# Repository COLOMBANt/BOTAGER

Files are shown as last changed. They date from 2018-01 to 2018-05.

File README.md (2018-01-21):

# BOTAGER

polytech logo polytech 
Ce projet est réalisé dans le cadre de la formation de prépa intégrée de Polytech'Nice Sophia 

<h1>Description</h1>

Le BOTAGER est un robot qui pourra se déplacer sur un potager pour planter différentes plantes.
L'utilisateur donne les instructions au robot à travers une application smartphone, il peut choisir les types de plantes, et leur disposition sur le terrain.

Le robot quand à lui pourra se repérer sur le terrain grâce à 4 piquets plantés sur chaque coin pour délimiter le terrain

<h1>Matériel</h1>

+ 4 modules HELTEC LoRa Bluetooth (1 pour chaque piquet)  
+ Carte Arduino  
+ Un système de sélection de graines
+ Squelette du robot
+ Un smartphone

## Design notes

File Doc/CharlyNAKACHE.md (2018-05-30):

# Cahier de suivi du projet de Charly NAKACHE

* Séance du 20 Décembre 2017 

J'ai formé mon groupe avec Dimitri DAVID et Thomas COLOMBAN. 
Nous sommes partis sur une idée de robot piloté par smartphone qui servirait à planter un potager.
L'utilisateur pourra choisir l'organisation du potager (Type de graines/Emplacement des plantes)

Nous avons défini le planning des prochains mois, nous nous sommes répartis les différentes tâches et
nous avons fait un diagramme fonctionnel du projet.

* Séance du 12 Janvier 2018
 
 Lors de la répartition des tâches j'ai choisi le côté plus mécanique que informatique, c'est à dire le
 chassis du robot, sons système de propulsion mais aussi le tri des différents graînes et la méthode pour les planter.

 J'ai effectué des recherches pour avoir une idée du squelette du robot, je pensais à un chassis plat (pour placer
 simplement les composants), 4 grosses roues avec des pneus "tout-terrain" (chenilles non nécéssaires pour un si petit
 robot), d'une taille d'environ 15cm² pour placer les différents composants que j'aurai besoin pour le plantage, mais
 aussi ceux que mes collaborateurs auront besoin  de placer sur le robot.
 
 J'ai alors demandé à Monsieur Ferrerro si il y avait des squelettes de robots à disposition et il m'en a proposé un qui
 me parait très bien pour ce que j'ai à faire, les moteurs sont déjà placés et soudés, les pneus sont bien larges et ont
 l'air d'avoir une bonne adhérance à la terre.

* Séance du 19 Janvier 2018

J'ai commencé à imaginer le système de tri des graines et de méthode de plantation.
Les graines seront dans des compartiments différents placés en ligne, un actionneur linéaire et une pompe à air (attachés à un socle)
se déplaceront au dessus des différents compartiments grâce à un système de rails reliés à un moteur.
Pour attraper seulement une ou deux graines, j'utilise la pompe à air, il y aura un petit orifice au bout de mon système pour que
la graine soit aspirée et reste collée au bout du système.
J'ai donc fait des recherches pour les différents composants que j'ai besoin.

* Séance du 23 Janvier 2018

Nous avons fait notre présentation orale.
Durant la semaine j'ai réfléchi à un autre système pour le déplacement de mon actionneur linéaire et de la pompe, je pensais à un
système de courroie et poulies où le socle serait accroché. J'ai donc fait des recherches pour la courroie avant d'envoyer ça
Mr Masson.

* Séance du 6 février

Durant la séance, j'ai fait différents schémas pour réfléchir et visualiser mon mécanisme. De plus, j'ai fait des recherches sur
les moteurs de la pompe à air que j'ai commandé, je me suis rendu compte que cette pompe était finalement une souffleuse 
et non pas une pompe. Par chance, Mr Masson disposait d'une pompe (un peu plus puissante en plus) que j'ai pu récupéré.

* Séance du 22 février

J'ai continué les recherches  sur la pompe et l'utilisation de cette dernière avec le uln2803.

* Séance du 15 mars 

Modélisation rapide en 3d du robot.
Mr. Masson nous donne un moteur pas à pas.
Problème avec actionneur linéaire, erreur dans les dimensions.
Recherches sur le type de batterie nécessaire et la capacité.

* Séance du 27 mars

Diaporama et présentation orale.
Mr. Masson nous donne une batterie.

* Séance du 04 avril

En attente de l'actionneur j'ai aidé dimitri pour des recherches pendant le cours.
Recherches sur le fonctionnement de la batterie.
Recherches sur le moteur pas à pas et pont en H.

* Séance du 17 avril

Sofab :
on a démonté et remonté le robot en y ajoutant la structure nécessaire (bois).
Impression de pièces 3D pour les graines et les rails (pour le déplacement de l'actionneur)

* Séance du 02 mai

Modélisation d'un système 3d permettant de fixer l'actionneur.
Sofab :
Ajout de la courroie fixée au rail, et de pièces en bois pour fixer le moteur pas à pas, mais aussi de cales pour tendre la courroie.

* Séance du 07 mai

Problèmes concernant la pièce qu'on voulait fixer au bout de l'actionneur pour y mettre le tube de la pompe à air,
l'imprimante 3d ne peut faire un objet aussi petit et précis.
Plus tard, problèmes de couple avec le moteur pas à pas, il n'y a pas assez de puissance.

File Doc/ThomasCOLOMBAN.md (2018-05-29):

# Cahier de suivi du projet de Thomas COLOMBAN

* Séance du 20 Décembre 2017 

J'ai formé mon groupe avec Dimitri DAVID et Charly NAKACHE. 
Nous sommes partis sur une idée de robot piloté par smartphone qui servirait a planter un potager.
L'utilisateur pourra choisir l'organisation du potager (Type de graines/Emplacement des plantes)

Nous avons défini le planning des prochains mois et nous nous sommes répartis les différentes tâches et
nous avons fait un diagramme fonctionnel du projet.

* Séance du 12 Janvier 2018 

Dans le cadre du projet, je me suis occupé de deux sous-parties :
-	L’application smartphone sous Android qui permet à l’utilisateur de choisir le type de graine à planter, et la disposition des graines sur le champ. 
-	La gestion des 4 moteurs à courant continu pour faire se déplacer le robot.

La plus grande partie de mon travail a été de programmer une application sous Android sur laquelle l’utilisateur peut choisir où et quoi planter comme graines et qui ensuite envoi les informations en Bluetooth à la carte Arduino du robot.
Pour cela j’ai choisi de tout coder moi-même que ce soit le visuel de l’application ou le protocole Bluetooth.
J’ai donc réalisé l’application avec le logiciel Android Studio qui permet de coder des applications pour Android.
Premièrement j’ai dû suivre plusieurs tutoriels pour comprendre le fonctionnement du logiciel, qui est très puissant mais donc assez complexe à prendre en main.

Voici les premiers visuels de l'appli

Image appli 1

Image appli 2

Image appli 3

J’étais partis du principe que le rectangle central représentait le champ, et grâce au bouton inventaire situé en bas on ouvrait l’inventaire avec les différentes plantes (voir 3ème image).
Ensuite en appuyant sur un icone on pourrait faire glisser la plante là où on le souhaite sur le champ.
Il y a aussi un bouton en haut à gauche pour faire apparaitre la liste des appareils Bluetooth.

* Séance du 19 Janvier 2018                        

Rédaction du README.md

J'ai fait ma partie PowerPoint dans la présentation du 23/01.
J'ai aussi commencé l'application sous Android Studio.

* Séance du 23 Janvier 2018

Présentation Orale  
Application sous AndroidStudio

* Séance du 6 février

Après plusieurs semaines passées sur le logiciel j’ai décidé de simplifier certaines fonctions de l’application, à cause de leur complexité et par manque de temps, et d’en ajouter d’autres.
Voici les nouveaux visuels:

interface_1

interface_2

Le champ où l’on va planter les graines sera modélisé par une grille de 16 boutons, car pour simplifier nous partons du principe que le champ sera divisé en 16 carreaux et il est possible de planter une graine dans chaque.
A chaque appui sur un bouton ce dernier change de couleur, pour signifier le type de plante.
Au départ tous les boutons sont grisés et c’est l’utilisateur qui choisis sur quoi appuyer en fonction du résultat qu’il veut. Il y a aussi un bouton Effacer (la croix en haut à gauche) qui va remettre toutes les cases grises, et un bouton Envoyer qui va récupérer la valeur associée à chaque bouton et l’envoi au robot par Bluetooth. 

* Séance du 22 février

Fin de la partie XML de l'application

28942654_430170724103745_731970666_o

28822561_430170720770412_221739668_o

* Séance du 15 mars 

Partie Bluetooth en Java

* Séance du 27 mars

Diaporama et présentation orale 

* Séance du 04 avril

J'ai commencé la partie de gestion des moteurs :
- Recherche de la documentation constructeur  
- Schéma de câblage de l'arduino, de la batterie et de la carte de gestion des moteurs  
    
Mon travail consistait donc à faire les fonctions de base Avancer, Reculer, Rotation et Stop du robot.
J’ai donc dû cabler ensemble les moteurs, la carte L298 V3 et une arduino Uno, et ensuite coder un programme arduino pour réaliser ces fonctions.
    
Ebauche du câblage:
30849423_450469662073851_1439568072_o

* Séance du 17 avril

J’ai tout d’abord rencontré quelques difficultés pour comprendre le fonctionnement de la carte L298 V3. Il y a peu de documentation sur internet de cette carte car une autre carte la L298 V1 est beaucoup plus connue et remplit la même fonction avec seulement 2 entrées moteur au lieu de 4 pour la L298 V3. J’ai donc principalement raisonné par déduction en me basant sur la documentation constructeur de la L298 V1 et j’ai effectué de nombreux tests pour comprendre son fonctionnement.

Soudure des différentes parties de la carte
Problème avec l'alimentation de la carte L298N V3

* Séance du 02 mai

Schéma de câblage final:

cablage

Test de rotation du robot avec le programme du magnétomètre (partie de Charly Nakache)
Le robot arrive bien à se repérer dans l'espace(orientation) et à tourner jusqu'à l'angle indiqué

* Séance du 07 mai

Réglage des derniers bugs sur l'application Android

* 20 mai 

Partie Bluetooth terminée  
Partie gestion des moteurs finie  
Et tout fonctionne !!

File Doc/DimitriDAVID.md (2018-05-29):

# Cahier de suivi du projet de David Dimitri

* Séance du 20 Décembre 2017 

J'ai formé mon groupe avec Thomas COLOMBAN et Charly NAKACHE. 
Nous sommes partis sur une idée de robot piloté par smartphone qui servirait a planter un potager.
L'utilisateur pourra choisir l'organisation du potager (Type de graines/Emplacement des plantes)

Nous avons défini le planning des prochains mois et nous nous sommes répartis les différentes tâches et
nous avons fait un diagramme fonctionnel du projet.

* Vacances de Noël 

J'ai recherché des solutions et voies à explorer pour reussir a positionné le robot dans l'espaces.

* Semaine du 12 Janvier 2018 : 

Familiarisation avec les module LoRa, et élaboration du github.

* Semaine du 19 janvier 2018 :

Réalisation du modèle de notre robot sur inventor.
Premier test des modules Heltec Lora.

* Semaine du 26 janvier 2018 :

Réalisation d'une première maquette virtuelle sur AutoDesk.
Début de la rédaction d'un code de trilatération.

* Semaine  du 2 février 2018 :

Réception des modules commander, premier pas avec eux et encore rédaction du programme de trilatération.

* Semaine du 9 février 2018 :

Après test de mon code de trilatération, je me rend compte que la précision des mesures pouvaient mettre dans un cas où l'étude de l'intersection de 3 cercles ne comportais pas de solutions. Je suis donc à la recherche du solution alternative.

* Semaine du 15 février 2018 :

Après des recherches j'essaye de trouver une méthode utilisant la barycentre pondéré des 3 poteaux pour trouver l'emplacement du mobile. La tache la plus compliqué dans cela est de trouver des coefficients permettant de retrouvé l'emplacement dans tout les cas, je suis donc actuellment en trin d'étudier diverses solutions possibles.

* Semaine du 22 février 2018 :

Beaucoup de problème pour trouver une methode permettant la résolution sytematique du problème. Je pense négliger cette partie pour le moment, je vais pour l'instant faire seulement un solveur d'équation puis si le temps me le permet essayer de retrouver une solution a la fin. Je rencontre aussi beaucoup de probleme avec les codes, les variables numériques ont tendances à s'arrondir lors de convertion d'une façon qu'il ne devrais pas être.

* Semaine du 1 Mars :

Des problèmes d'interference entre les modules, les messages s'enmêle. Je cherche une solution pour s'incroniser les différents envoie de données.

* Semaine du 7 Mars :

Probleme regler, en utilisant des intervalles et la fonction millis. Le temps d'acquisition est certes plus long, mais cela fonctionne parfaitement. Aussi, il me semble qu'un des module presente un default, il refusent de se compiler, même si le codes est fonctionneles sur les autres modules.

* Semaine du 14 mars :

Sur la proposition de monsieur Ferrero je vais integrer une variation de frequence d'envoie dans le systeme afin d'optimiser la mesure de distance. Aussi, il m'as mit a dispostion ses codes qu'il utilisent sur les même modules que moi, domage que ce soit si tard.

* Semaine du 21 mars :

 Finissions du code pour trouver la postion du robot, celui marche même avec les écart de mesures des modules bluetooth.
 Redaction d'un code pour rassembler les données sur le robot.
 
 * Semaine du 28 Mars :
 
 Dessins des plans des pièces à découper ou à imprimer pour la construction de la structure du robot.
 
 * Semaine du 5 Avril :

  Assemblage de la structure du robot avec Charly , et teste des différents éléments mobiles (actionneur, moteur pas à pas, ...)
  
  * Semaine du 12 Avril :
  
  Début de rédaction du programme pour venir chercher et déposer la graine que l'utilisateur à choisit.
  
  * Semaine du 20 Avril :
  
  Etablissement d'une fonction permettant de positionner le robot dans un certain angle choisie, par rapport au repère.
  Utilisation du magnétomètre.
  
  *Semaine du 30 avril :
  
  Nouveau problème dans la communication entre les modules LoRa,source du probleme inconnue, j'ai du reprendre les codes.
  
  * Semaine du 1 mai :
  
  Redaction du programme de deplacment d'un point A à un point B.
  
  * Semaine du 7 mai :
  
  Test de déplacment du robot. Echec à cause de mesure de RSSI variant de plusisuer dizaies de décibels.
  
  * Semaine du 14 mai :
  
  idem que la semaine passé, nous n'arrivons pas à solutionner le problème.
  
  * Semaine du 21 mai :
  
  Redaction d'un programme de démonstration n'utilisant pas la localisation
  
  * Semaine du 28 mai :
  
  Compte rendu et préparation de l'oral, denière finissions, tournage de la vidéo de présentation.

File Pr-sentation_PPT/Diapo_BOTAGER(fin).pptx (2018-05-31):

## BOTAGER

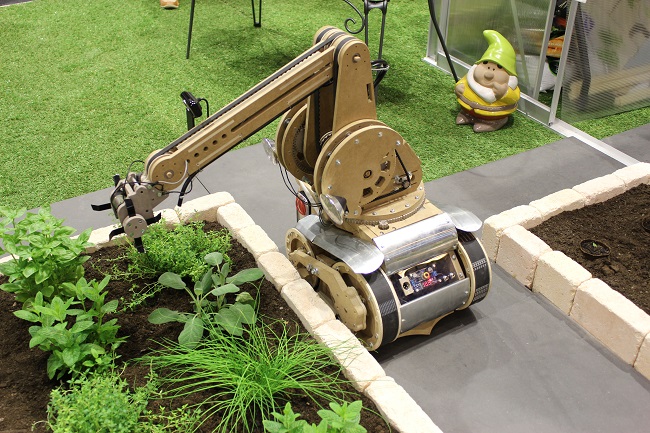
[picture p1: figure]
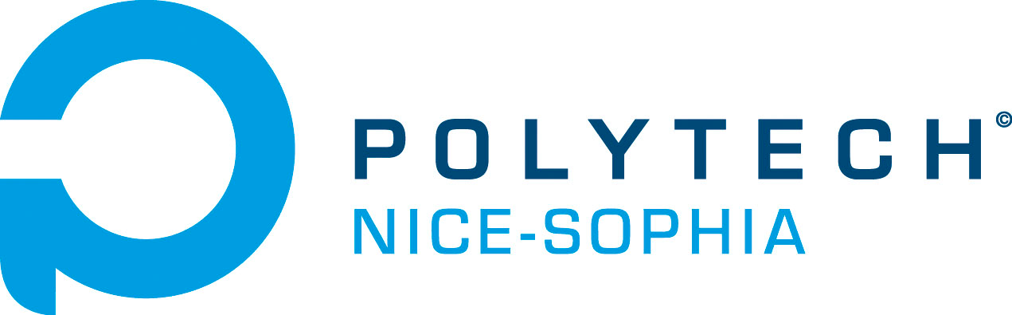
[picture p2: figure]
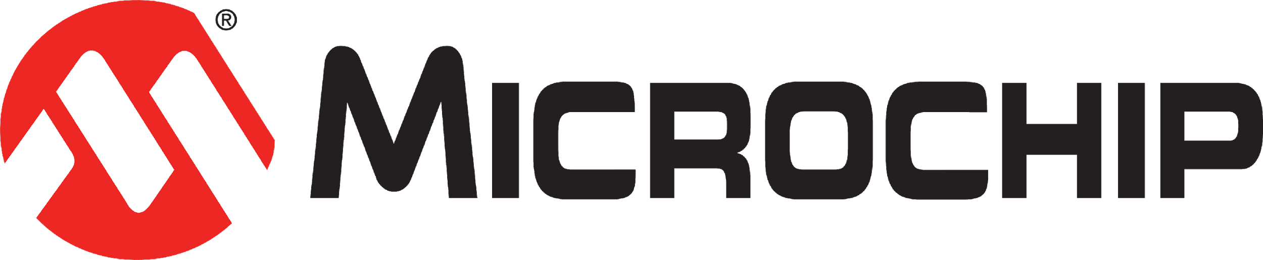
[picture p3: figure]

DAVID Dimitri
NAKACHE Charly
COLOMBAN Thomas

## NOTRE PROJET

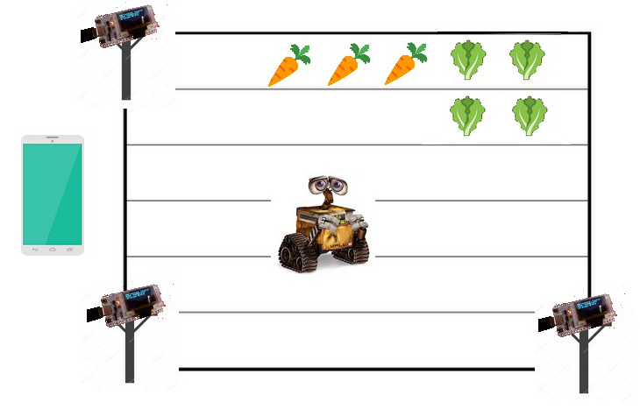
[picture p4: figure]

## REPARTITION DES TACHES

- Application smartphone/Gestion des moteurs Thomas COLOMBAN
- Positionnement/Repérage du robot dans l’espace Dimitri DAVID
- Assemblage du robot Charly NAKACHE

## APPLICATION

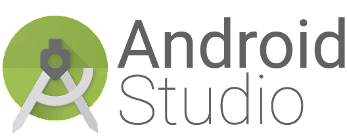
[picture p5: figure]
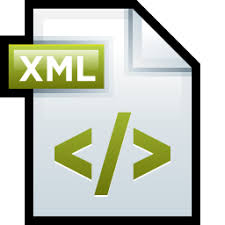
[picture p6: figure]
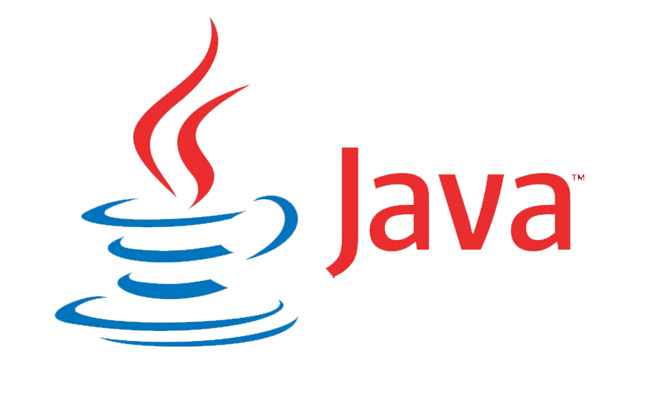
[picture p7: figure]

## APPLICATION

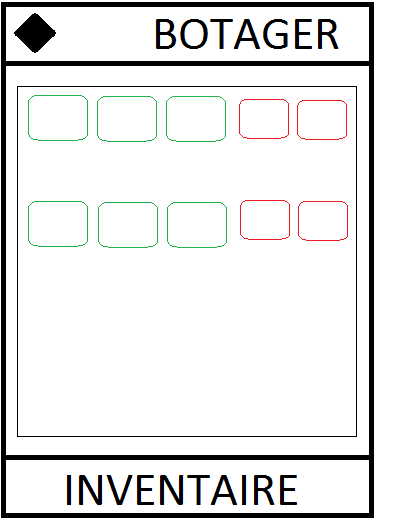
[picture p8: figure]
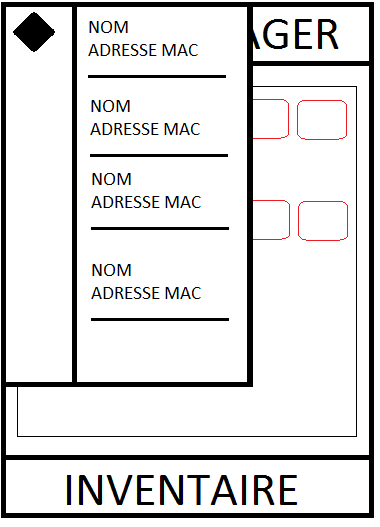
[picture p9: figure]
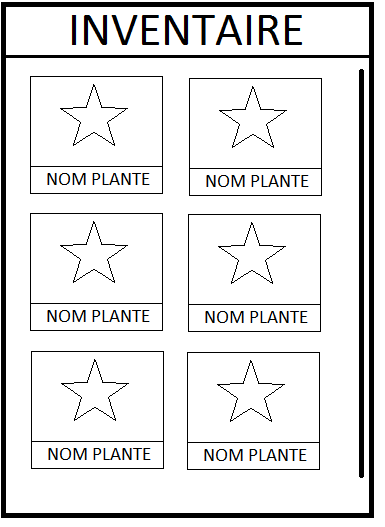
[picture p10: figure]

## APPLICATION

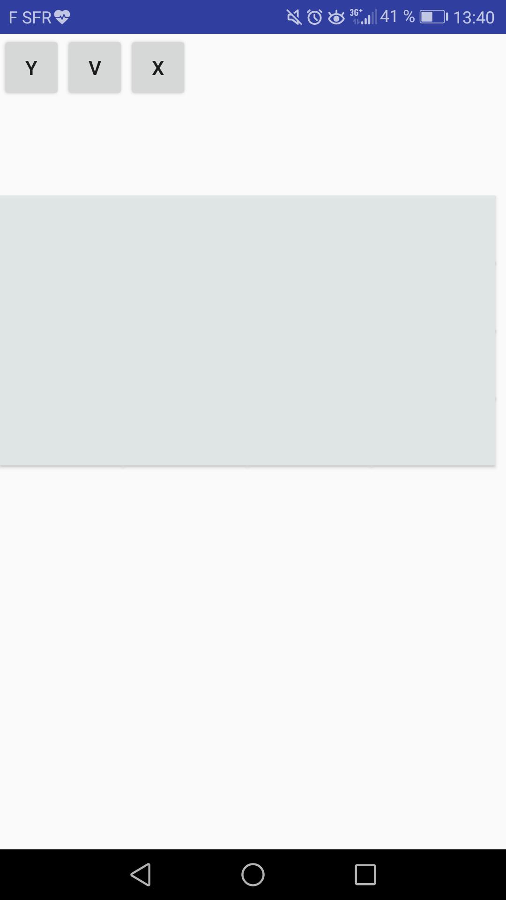
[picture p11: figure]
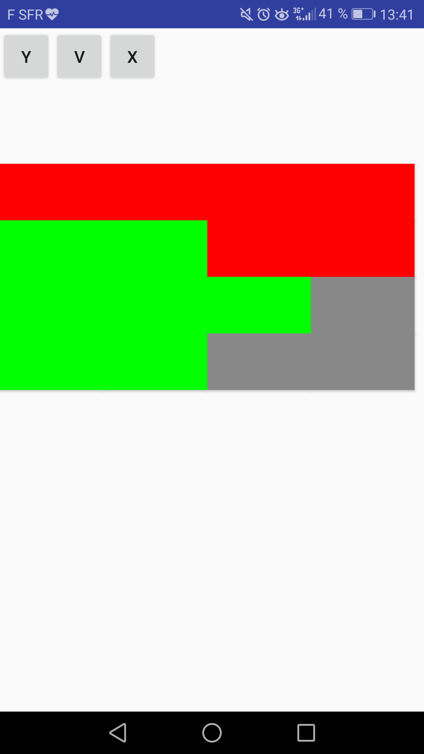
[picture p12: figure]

## APPLICATION

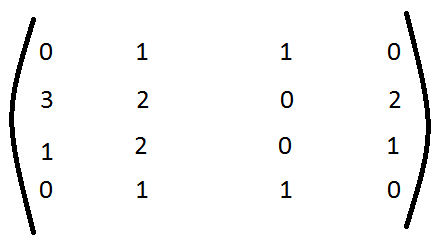
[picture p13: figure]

0: Rien
1: Salade
2: Tomates
3: Oignons
Etc …

## APPLICATION

- Simplification de l’application
- Complexité de la liaison Bluetooth

PROBLEMES :

## GESTION DES MOTEURS

- Avancer();
- Reculer();
- Orientation( Angle );
- Stop();

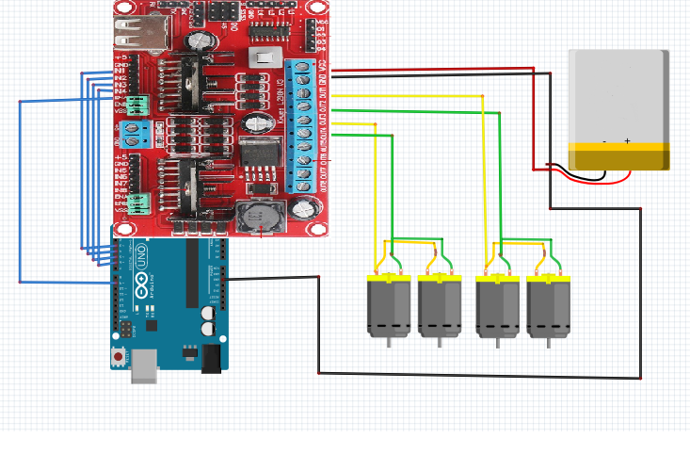
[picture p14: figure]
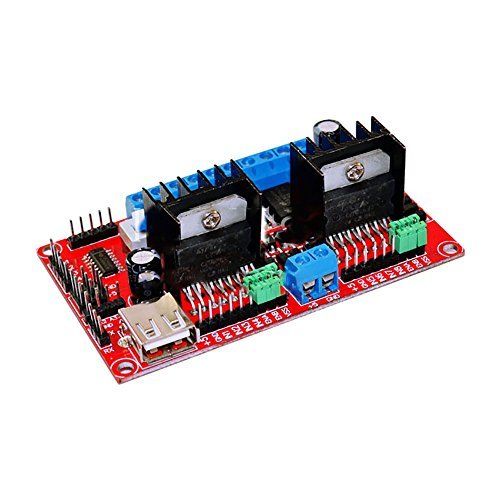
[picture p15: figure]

## POSITIONNEMENT

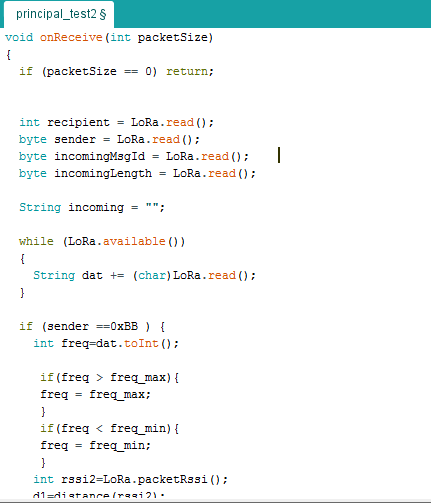
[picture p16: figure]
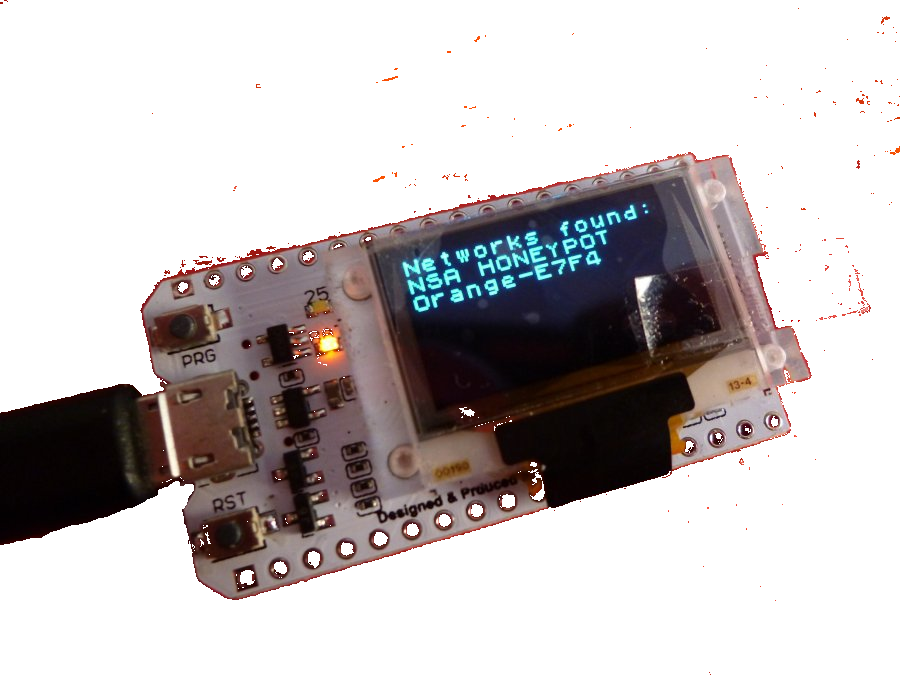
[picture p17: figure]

## POSITIONNEMENT

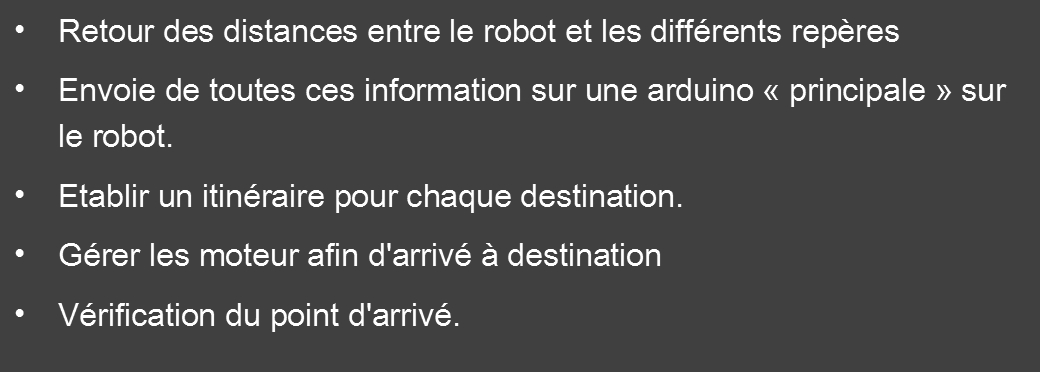
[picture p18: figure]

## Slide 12

POSITIONNEMENT

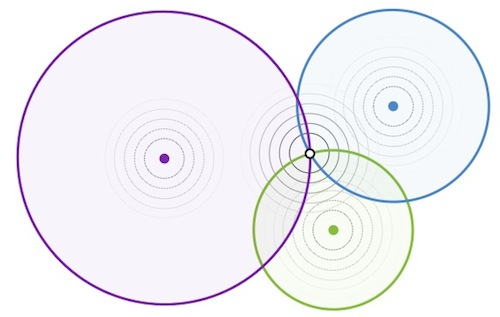
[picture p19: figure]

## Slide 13

POSITIONNEMENT

PROBLEMES :

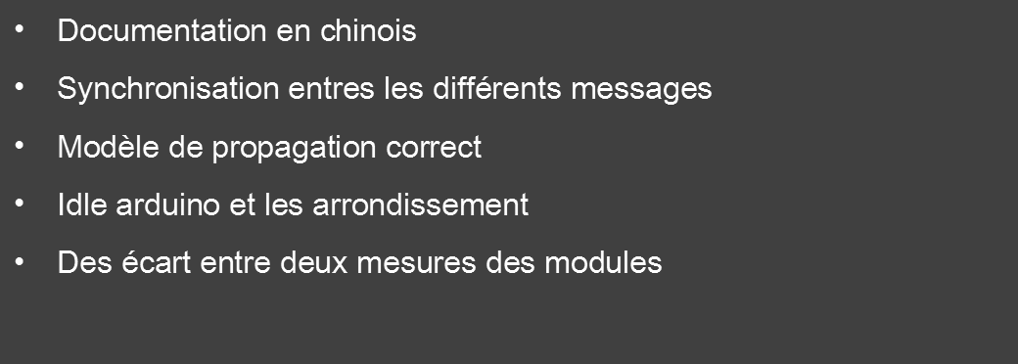
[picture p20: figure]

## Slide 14

NAVIGATION

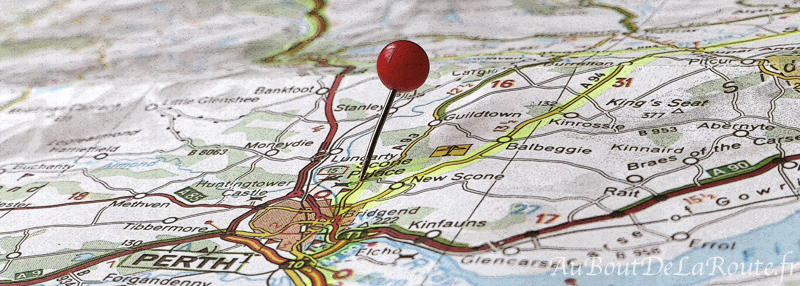
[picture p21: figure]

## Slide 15

POSITIONNEMENT

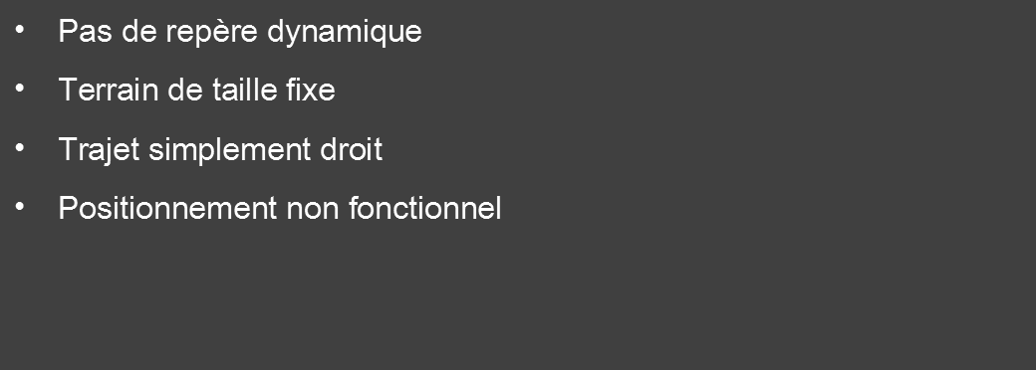
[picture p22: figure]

## ASSEMBLAGE / GESTION DES GRAINES

- Recherches sur la propulsion / forme du robot
- Plans du robot et système de plantation des graines
- Modélisation et impression de pièces 3D

## Mes problèmes

ASSEMBLAGE / GESTION DES GRAINES

- Changements concernant la structure du robot
- Commande de pièces
- Calculs pour certains composants

## CONCLUSION

- Apprendre le travail d’ingénieur
- Apprendre de nombreuses connaissances
- Projet trop ambitieux

## TEST IRL

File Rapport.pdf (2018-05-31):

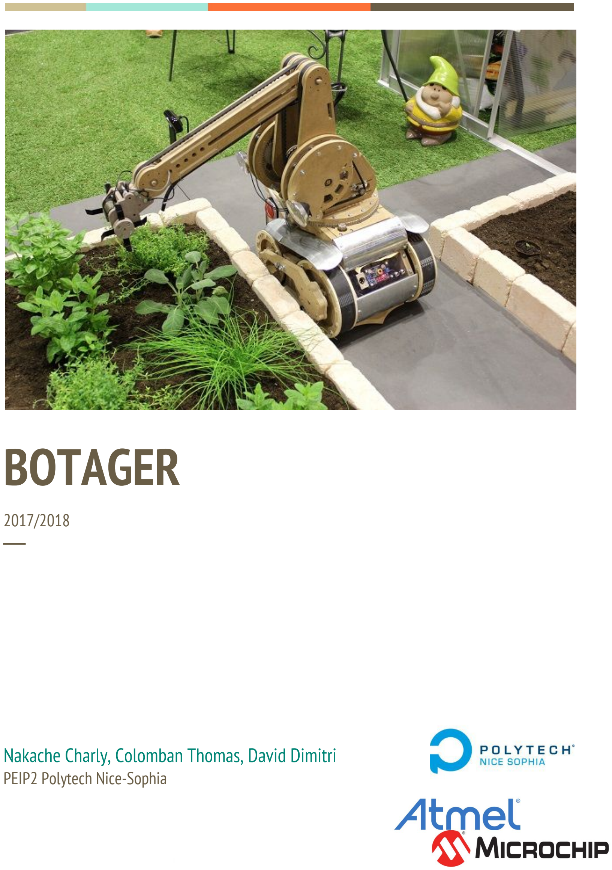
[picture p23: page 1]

# BOTAGER

2017/2018
─

Nakache Charly, Colomban Thomas, David Dimitri PEIP2 Polytech Nice-Sophia

## Sommaire :

I/Notre Projet :

2/Objectifs :

3/Matériel utilisé :

4/Fonctionnement et schéma :

5/Problèmes rencontrés :

6/Conclusion :

## Notre Projet :

Concept :
Nous étions partis sur la recherche d’un moyen permettant de faciliter et de rendre plus accessible les plaisirs du jardin. C’est pourquoi nous avons rapidement choisi de concevoir un robot permettant d’effectuer des tâches répétitives. Nous avons donc centré toutes les fonctionnalités de ce robot autour de ce leitmotiv. Ce robot pourra donc planter des graines au sein d’un terrain délimité à des emplacements définis via une application téléphone. Le repérage s’effectuera via des poteaux de délimitation.

## Our Project :

Concept :
We were looking for a method to simplified and make more accessfull the pleasure of having a little garden. That why we quickly choose to try to conceived a bot that can carry out repetitives task. So we have center all the features of this bot around this goal. This bot will be able to plant seeds anywhere in a delimited ground in spots defined with a smartphone app. The positioning will be using post to landmark and spot the bot.

## Nos Objectifs :

Objectifs à réaliser :
Afin de mener à bien les actions qui lui sont demandé, certaines fonctionnalités s'imposait, en voici la liste :
-Une application téléphone permettant de dialoguer avec le robot afin de lui transmettre ses instructions. Cette application devra être capable de modéliser le terrain sur lequel le robot évoluera, permettre à l’utilisateur de sélectionner les emplacements des plantations et également lui permettre de choisir quelles variétés de plantes il souhaite planter.

-Un châssis permettant au robot d’évoluer dans la terre voir la boue, lui permettant également d’être autonome en énergie, d’apporter avec lui une variété de graines, qui seront sélectionnées d’après les volontés de l’utilisateur et enfin il devra être également capable de transporter un système permettant la plantation.

-Un système de repérage permettant au robot de connaître sa position à tout moment, afin de pouvoir naviguer à l’emplacement voulu. L’utilisation du GPS pour cette tâche est écartée car la résolution nécessaire à cette fonction est beaucoup plus précise. Enfin dans l’idéal ce système aurait été complètement modulable et aurait pû s'adapter à toutes les configurations possibles.

Objectifs atteints :
Au vue de la complexité des objectifs que nous nous étions fixés, nous avons été obligé de simplifier certains d’entre eux. Voici un état des lieux des fonctionnalités opérationnelles à ce jour :

- La modularité des terrains d’action du robot ont été simplifié, nous nous sommes donc attelés à le faire fonctionner sur un terrain carré fixe d’une taille de 12x12 mètres
-Les emplacements de plantations se sont vue réglementés et définie au nombre de 16. Il s’agit donc de zone de 3x3m que le robot essayera d’atteindre en leur centre. Ce changement vient de difficulté dans le codage de l’application, ainsi que de problème de précision dans le repérage du robot. Ses emplacements prédéfinis nous permettent ainsi d’avoir une marge d’erreur qui est en adéquation avec les limites techniques des solutions adoptées.
-Suite à des problèmes qui nous semblent insolvables, le positionnement n’est à l’heure actuel pas fonctionnel, ce qui implique que la navigation autonome du robot est impossible.
-Enfin il nous semblait impossible dans le temps imparti de réaliser un vrai système de plantation, vu le gabarit de notre robot, ainsi le système mit en oeuvre aura seulement la possibilité de poser au sol la graine choisi par l’utilisateur.

## Matériel utilisé :

Sur le robot :
-Magnétomètre HMC5883L : Ils sont utilisés pour connaître l’orientation du robot par rapport aux différents points de repère.

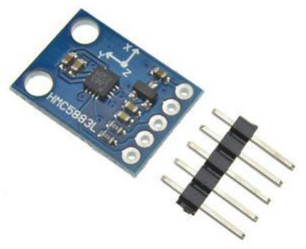
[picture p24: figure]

-Moteur pas à pas : Utilisé pour permettre le mouvement du chariot sur ses rails.

-Actionneur linéaire : Utilisé pour descendre chercher une graine dans les réceptacles puis les déposer au sol.


-Pont en H : Utilisé pour alimenter le moteur pas à pas


-Carte L298 V3: Utilisée pour alimenter les 4 moteurs CC du robot

-Pont en H : Utilisé pour alimenter la pompe à graine et l’actionneur linéaire.

-Batterie Li-po : Utilisée pour fournir une


alimentation 12V et assez de réserve d’énergie pour permettre au robot d'effectuer sa tâche

-Arduino Mega :
Carte peut être surdimensionnée, mais permettant plusieurs communications séries et offrant suffisamment de pin.


-Module Heltec LoRa 433kHz :
Permette d’envoyer des messages de positionnement aux poteaux et également de recevoir les informations calculées par ceux-ci.


-Module HC-06 :
Effectue une connection entre l’application smartphone et le robot

Sur les poteaux :

-Module Heltec LoRa 433kHz :
Utilisé pour recevoir les messages du robot, et déduire sa distance en utilisant les pertes de puissance du signal reçu par rapport à celui
envoyé.


-Pile 5V : Utilisée pour fournir l’alimentation nécessaire aux carte.

## Fonctionnement et schéma :

Positionnement :
Le positionnement nécessaire au fonctionnement du robot devait être beaucoup plus précis que celui offert par un GPS. En effet le GPS offre une incertitude de l’ordre de la dizaine de mètre. Ce qui est beaucoup trop pour la taille des terrains d’action du robot ( douzaine de mètre de long). Nous avons donc choisit d’utiliser la trilatération afin de connaître la position du robot par rapport aux points de repère. Nous avons donc choisi de positionner 3 poteaux de repérage autour du terrain d’action du robot. Ceux ci sont placés de telle manière à créer un repère cartésien sur ce terrain. Notre système mesure donc en permanence la distance du robot par rapport à chacun de ses points. Il est ensuite très facile de remonter à la position du robot sur le repère via les calculs suivant :

X = 2 x X1

D −D +X

2
1

2
2

2
1

Y = 2 x Y 2

D −D +Y

2
1

2
3

2
2


Il ne nous restait donc plus qu’à trouver le moyen de mesurer cette distance de manière assez précise. Nous avons décidé d'utiliser la différence de puissance d’un signal bluetooth entre son émission et sa réception. Cette valeur, aussi appelée RSSI (Received Signal Strength Intensity), exprimé en décibel, permet de remonter à une estimation de la distance avec une précision de l’ordre du mètre. Pour ce faire il suffit d'utiliser une formule simplifiée de modèle de propagation d’onde électromagnétique. Voici la formule utilisée:

d = 10 10n

P−RSSI

Où :- P représente la valeur de RSSI à 1m.
-n indice propre au milieu de propagation (nous avons pris 2). -d Distance entre l’émetteur et le récepteur.

Application Android :

L’utilisateur peut choisir le type de graines à planter ainsi que leurs emplacements via une application Android. L’application se compose donc d’une interface qui représente un potager avec 16 carrés qui peuvent prendre 3 couleurs différentes pour représenter 3 types de graines.
A chaque appui sur un des carrés la valeur et la couleur de ce dernier change pour symboliser une graine différente. Une barre est située au dessus de cette interface avec 3 boutons : un pour faire une remise à zéro du potager ( toutes les cases deviennent grises), un pour envoyer l’état du potager au robot et un bouton pour la liaison Bluetooth.
Ce dernier affiche la liste des périphériques Bluetooth du smartphone et permet donc de se connecter au module HC-06 du robot.
L’application a été développée entièrement sur le logiciel Android Studio en Java pour la partie algorithmique/liaison Bluetooth et en XML pour la partie visuelle.

Flux de données Bluetooth (Poteaux):

En plus de la communication bluetooth avec le téléphone, un réseaux qui cette fois ci opère pour le positionnement à également était mis en place. Ce réseaux utilise la technologie LoRa. Les échanges sur ce réseaux s’opère de la façon suivante :
1)Le robot émet périodiquement des messages à l’attention des 3 poteaux, celui précise que c’est lui l'émetteur grâce à une “adresse ip”.
2) Les poteaux, vérifie que le message reçu viens effectivement du robot, puis mesure la valeur de RSSI et en déduisent la distance les séparant du robot.Il envoie ensuite cette information au poteau principal.
3)Le poteaux principal reçoit toute les information de distance, et les transmet au robot sous la forme d’un unique message.
4)Le robot associe chaque distance à chaque poteau, et déduit sa position grâce aux calculs préciser au dessus.


Gestion des déplacements :

Les moteurs sont commandés par l’Arduino Mega qui envoie ses instructions au module L298 V3. Ce dernier est chargé d’alimenter les 4 moteurs CC du robot, et fait office de double pont en H et de diode de roue libre. Pour aller de la position actuel à celle voulue par l’utilisateur, le robot va tout d’abord effectuer une rotation pour pointer vers l’endroit choisi, puis avancer tant que sa position ne correspond pas à celle voulu. Nous avons, compte tenue de la précision des mouvement et du positionnement mit une marge d’erreur de plus ou moins 50 cm par rapport à l’emplacement désiré.

## Problèmes rencontrés :

Positionnement :

Le principal problème rencontré sur cette partie à été de bien faire fonctionner chaque module en même temps. En effet la communication de 5 modules en même temps favoriser les interférence que faussais le contenue naviguant entre deux modules. Nous avons finalement trouvé le moyenne d’éviter ceux la, en imposant une delais aléatoire de une à 2 sec entre chaque message émis par chaque module, afin de limiter le risque d’un envoie de deux messages simultané.

Le manque de documentation sur les modules que nous avons utilisé a également été une grande perte de temps, en effet la seule documentation complète que l’on a pu trouver été en chinois.
Enfin, et c’est ceux pourquoi le positionnement ne fonctionne pas sur la version finale du projet, nous avons eu énormément de problème avec les mesures de distance. En effet lors de la mesure de rssi, les modules semblait afficher des valeurs différente à chaque allumage des cartes, puis entre deux mesures, affichait deux valeur avec une différence de plusieur dizaine de décibels, ce qui nous empêche de pouvoir extraire suffisamment de donné afin de déduire l’emplacement du robot.

Dans la construction :

La construction à été source d’énormément de problème, en effet, le positionnement et le maintien du rail coulissant dans un axe permettant un glissement idéal à été extrêmement compliqué. Nous avons également du refaire plusieur pièces a cause de contrainte mécanique et technique liée au faite qu’elle était imprimé en 3d.

Application smartphone :

La partie Liaison Bluetooth avec le module HC-06 a été assez complexe à mettre en oeuvre étant donné que nous sommes partis de zéro et n’avons utilisé aucune librairie existante déjà programmée.
Après de nombreuses heures de documentations sur les protocoles Bluetooth ( recherche du module HC-06, appairage, envoi du flux de données, …) la majorité des difficultés se sont résumées à des erreurs de compilation.

## Conclusion:

Tout d’abord, ces 5 mois de projet nous ont permis de collaborer en équipe, d’effectuer des recherches, de résoudre des problèmes, de s’organiser,et d’apprendre de nouvelles connaissances.

La quasi totalité des objectifs de départ ont été réalisés, à savoir un robot commandé par une application qui se déplace sur un terrain et sème les graines voulues. Seule la partie repérage et positionnement du robot n’a pu être accomplie en raison du manque de précision des modules LoRa.

Perspectives et amélioration :
Les éléments que nous avons dû simplifier par manque de temps pourraient être réalisés : un système permettant de planter les graines dans le sol et non simplement de les faire tomber, un réservoir à graines plus conséquent pour permettre plus de choix, utiliser d’autres modules de positionnement avec une précision accrue.
Nous aurions pu aussi mettre en place un programme qui calcule la superficie du champ avec les distances intra-poteaux et qui envoi cette information à l’application smartphone pour que cette dernière adapte en fonction l’interface proposé à l’utilisateur.

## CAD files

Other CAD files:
Version Finale/Pieces/Chassis.ipt
Version Finale/Pieces/EMBOUT.ipt
Version Finale/Pieces/Montant.ipt
Version Finale/Pieces/Moteur courroie.ipt
Version Finale/Pieces/Moteur roue.ipt
Version Finale/Pieces/Moteur roue_MIR.ipt
Version Finale/Pieces/Moteur roue_MIR1.ipt
Version Finale/Pieces/Moteur roue_MIR_MIR.ipt
Version Finale/Pieces/Pointe.ipt
Version Finale/Pieces/Pompe.ipt
Version Finale/Pieces/Robot.iam
Version Finale/Pieces/Roue.ipt
Version Finale/Pieces/Roue_MIR.ipt
Version Finale/Pieces/Roue_MIR1.ipt
Version Finale/Pieces/Roue_MIR_MIR.ipt
Version Finale/Pieces/Support embout.ipt
Version Finale/Pieces/Support moteur pas a pas.ipt
Version Finale/Pieces/Support poulie.ipt
Version Finale/Pieces/actionneur linéaire.ipt
Version Finale/Pieces/bague.ipt
Version Finale/Pieces/haut support.ipt
Version Finale/Pieces/receptacle.ipt
Version Finale/Pieces/support capilaire.ipt

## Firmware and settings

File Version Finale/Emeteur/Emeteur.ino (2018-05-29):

/*
  LoRa Multiple Communication

  This example provide a simple way to achieve one to multiple devices
  communication.

  Each devices send datas in broadcast method. Make sure each devices
  working in the same BAND, then set the localAddress and destination
  as you want.
  
  Sends a message every half second, and uses interrup method check
  the new incoming messages. Implements a one-byte addressing scheme,
  with 0xFD as the broadcast address. You can set this address as you
  want.

  The default interrupt pin in SX1276/8(DIO0) connected to ESP32's GPIO26

  Note: while sending, LoRa radio is not listening for incoming messages.
  Note2: when using the callback method, you can't use any of the Stream
  functions that rely on the timeout, such as readString, parseInt(), etc.
  
  by Aaron.Lee from HelTec AutoMation, ChengDu, China
  成都惠利特自动化科技有限公司
  www.heltec.cn
  
  this project also realess in GitHub:
  https://github.com/Heltec-Aaron-Lee/WiFi_Kit_series
*/

#include <SPI.h>
#include <LoRa.h>

// Pin definetion of WIFI LoRa 32
// HelTec AutoMation 2017 support@heltec.cn 
#define SCK     5    // GPIO5  -- SX127x's SCK
#define MISO    19   // GPIO19 -- SX127x's MISO
#define MOSI    27   // GPIO27 -- SX127x's MOSI
#define SS      18   // GPIO18 -- SX127x's CS
#define RST     14   // GPIO14 -- SX127x's RESET
#define DI00     26   // GPIO26 -- SX127x's IRQ(Interrupt Request)

#define BAND    433E6  //you can set band here directly,e.g. 868E6,915E6
#define PABOOST true
  
byte localAddress = 0xBB;     // address of this device
byte destination = 0xFD;      // destination to send to

String outgoing;              // outgoing message
byte msgCount = 0;            // count of outgoing messages
long lastSendTime = 0;        // last send time
int interval = 1000;          // interval between sends

void setup()
{
  Serial.begin(115200);                   // initialize serial
  while (!Serial);

  Serial.println("LoRa Duplex with callback");

  SPI.begin(SCK,MISO,MOSI,SS);
  LoRa.setPins(SS,RST,DI00);// set CS, reset, IRQ pins

  if (!LoRa.begin(BAND,PABOOST))
  {
    Serial.println("LoRa init failed. Check your connections.");
    while (true);                       // if failed, do nothing
  }

  LoRa.onReceive(onReceive);
  LoRa.receive();
  Serial.println("LoRa init succeeded.");
}

void loop()
{Serial.println("oui");
  if (millis() - lastSendTime > interval)
  {
    String message = "Hello World!";   // send a message
    sendMessage(message);
    Serial.println("Sending " + message);
    lastSendTime = millis();            // timestamp the message
    interval = random(1000) + 1000;     // 2-3 seconds
    LoRa.receive();                     // go back into receive mode
  }
  onReceive(LoRa.parsePacket());
}

void sendMessage(String outgoing)
{
  LoRa.beginPacket();                   // start packet
  LoRa.write(destination);              // add destination address
  LoRa.write(localAddress);             // add sender address
  LoRa.write(msgCount);                 // add message ID
  LoRa.write(outgoing.length());        // add payload length
  LoRa.print(outgoing);                 // add payload
  Serial.println("message envoye");
  LoRa.endPacket();                     // finish packet and send it
  msgCount++;                           // increment message ID
}

void onReceive(int packetSize)
{
  if (packetSize == 0) return;          // if there's no packet, return

  // read packet header bytes:
  int recipient = LoRa.read();          // recipient address
  byte sender = LoRa.read();            // sender address
  byte incomingMsgId = LoRa.read();     // incoming msg ID
  byte incomingLength = LoRa.read();    // incoming msg length

  String incoming = "";                 // payload of packet
  Serial.println("reception");
  while (LoRa.available())             // can't use readString() in callback
  {
    incoming += (char)LoRa.read();      // add bytes one by one
  }


  // if the recipient isn't this device or broadcast,
  if (sender==0xBA){Serial.println("oui");
    Serial.println(String(incoming));
    return;                             // skip rest of function
  }

  // if message is for this device, or broadcast, print details:
//  Serial.println("Received from: 0x" + String(sender, HEX));
//  Serial.println("Sent to: 0x" + String(recipient, HEX));
//  Serial.println("Message ID: " + String(incomingMsgId));
//  Serial.println("Message length: " + String(incomingLength));
//  Serial.println("Message: " + incoming);
//  Serial.println("RSSI: " + String(LoRa.packetRssi()));
//  Serial.println("Snr: " + String(LoRa.packetSnr()));
//  Serial.println();
}

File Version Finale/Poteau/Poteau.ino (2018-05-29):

#include <SPI.h>
#include <LoRa.h>
// definition des différents pin de bases de l'arduino-Lora
// Pin definetion of WIFI LoRa 32
// HelTec AutoMation 2017 support@heltec.cn 
#define SCK     5    // GPIO5  -- SX1278's SCK
#define MISO    19   // GPIO19 -- SX1278's MISO
#define MOSI    27   // GPIO27 -- SX1278's MOSI
#define SS      18   // GPIO18 -- SX1278's CS
#define RST     14   // GPIO14 -- SX1278's RESET
#define DI0     26   // GPIO26 -- SX1278's IRQ(Interrupt Request)

#define BAND    433E6  //you can set band here directly,e.g. 868E6,915E6
#define PABOOST true

String outgoing;              // message sortant
int rssi;
byte localAddress = 0xBC;     // adresse des poteaux (0xBE pour le poteau 1 et OxBC pour le poteau 2)
byte destination = 0xBA;      // destinataire
String incoming = "";
byte msgCount = 0;            //conteur de messages
long lastSendTime = 0;        // "Heure" du dernier envoie
int interval = 2000;          //interval entre chaque envoie
byte robot=0xBB;              //adresse du robot
int rssiE=-58;                //Valeur de Rssi à 1m

void setup()
{
  Serial.begin(115200);                   // initialisation serial
  while (!Serial);

  SPI.begin(SCK,MISO,MOSI,SS); //iniialisation du bluetooth
  LoRa.setPins(SS,RST,DI0);

  if (!LoRa.begin(BAND,PABOOST))
  {             // initialize ratio at 915 MHz
    Serial.println("LoRa init failed. Check your connections.");
    while (true);                      //En cas d'échec de la connection
  }

  Serial.println("LoRa init succeeded.");  //En cas de succes de la connexion
}

void loop()
{ /*On re-envoie un message avec un intervalle aléatoire compris entre 1 et 3 secondes
 (Pour éviter une interférence avec d'autres messages circulant sur les mêmes fréquences*/
  if (millis() - lastSendTime > interval) 
  {
    String message = String(distance(rssi)); //Renvoie la distance liée à la RSSI du message émit par le robot
    Serial.println(rssi);//Simplement pour controler
    sendMessage(message);
    
    lastSendTime = millis();            //actualise "l'heure" du dernier envoie
    interval = random(2000) + 1000;    // génère un nouvel interval
  }

 
  onReceive(LoRa.parsePacket()); //Action à effectuer à la réception
}

void sendMessage(String outgoing)
{
  LoRa.beginPacket();                   // start packet
  LoRa.write(destination);              // add destination address
  LoRa.write(localAddress);             // add sender address
  LoRa.write(msgCount);                 // add message ID
  LoRa.write(outgoing.length());        // add payload length
  LoRa.print(outgoing);                 // add payload
  LoRa.endPacket();                     // finish packet and send it
  msgCount++;                           // increment message ID
}

void onReceive(int packetSize)
{
   int recipient = LoRa.read();          // recipient address
  byte sender = LoRa.read();            // sender address
  byte incomingMsgId = LoRa.read();     // incoming msg ID
  byte incomingLength = LoRa.read();    // incoming msg length

  String incoming = "";
  if (packetSize == 0) return;          // if there's no packet, return
  if (sender ==robot) {rssi=LoRa.packetRssi();
  Serial.println(rssi);}
  while (LoRa.available()){
   incoming+= (char)LoRa.read();}

}

double distance (int rssi){
  float ratio=rssiE-rssi;
  double d=pow(10,(ratio/20));
  return(d);
}
